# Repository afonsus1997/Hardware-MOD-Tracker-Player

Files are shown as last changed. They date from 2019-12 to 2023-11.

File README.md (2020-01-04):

# Hardware MOD Tracker Player

## How to setup the ST ARM toolchain and IDE

* [Download the GNU toolchain from arm](https://developer.arm.com/tools-and-software/open-source-software/developer-tools/gnu-toolchain/gnu-rm/downloads)

* Uninstall old packages 

```sudo apt remove binutils-arm-none-eabi gcc-arm-none-eabi libnewlib-arm-none-eabi```

* Untar package to desired directory (ex: ~/arm/)

```tar -xjvf gcc-arm-none-eabi-xxxxxxxxx```

* Add toolchain to path

```export PATH=$PATH:"PATH TO TOOLCHAIN"/bin/```

* Test arm-gcc

```arm-none-eabi-gcc --version```

### VSCODE Setup

* Install ```stm32-for-vscode``` plugin

* Install ```Cortex-Debug extension``` plugin

### Install STLINK drivers

* Install Libusb

```sudo apt-get install libusb-1.0-0-dev```

* Install stlink ultility

```git clone https://github.com/texane/stlink stlink.git
cd stlink
make
#install binaries:
sudo cp build/Release/st-* /usr/local/bin
#install udev rules
sudo cp etc/udev/rules.d/49-stlinkv* /etc/udev/rules.d/
#and restart udev
sudo udevadm control --reload
```

### Install openOCD

```sudo apt-get install openocd```

### Install STM32CUBEMX (Optional but recommended)

For pinmaps, code generation, etc...

* [Download STM32CUBEMX](https://my.st.com/content/my_st_com/en/products/development-tools/software-development-tools/stm32-software-development-tools/stm32-configurators-and-code-generators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)

* unzip and cd to extracted

* Mark binary as executable

```chmod +x SetupSTM32CubeMX-x.x.x.linux```

* Run binary

```./SetupSTM32CubeMX-x.x.x.linux```

* Go through installation process on GUI

## How to flash STM project

### Using VScode

* Open project folder

* Open command list (Ctrl+Shift+p)

* Type ```stm32``` and choose an option

### Using make

* Build

```make -f STM32Make.make```

* Build and flash

```make -f STM32Make.make flash```

* Clean 

```make -f STM32Make.make clean```

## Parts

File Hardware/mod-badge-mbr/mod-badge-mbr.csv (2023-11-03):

Source: | E:\Github\Hardware-MOD-Tracker-Player\Hardware\mod-badge-mbr\mod-badge-mbr.kicad_sch
Date: | 11/3/2023 1:12:24 AM
Tool: | Eeschema 7.0.7
Generator: | C:\Program Files\KiCad\7.0\bin\scripting\plugins/bom_csv_grouped_by_value_with_fp.py
Component Count: | 71
Ref | Qnty | Value | Cmp name | Footprint | Description | Vendor | DNP
BT1 | 1 | Battery | Battery | mod:AAA-HOLDER-THD | Multiple-cell battery
C1, C2, C22 | 3 | 28uF | C_Small | Capacitor_SMD:C_0603_1608Metric | Unpolarized capacitor, small symbol
C3, C4, C6, C7, C8, C9, C10, C11, C12, C14, C17, C19 | 12 | 100n | C_Small | Capacitor_SMD:C_0603_1608Metric | Unpolarized capacitor, small symbol
C5, C13 | 2 | 1u | C_Small | Capacitor_SMD:C_0603_1608Metric | Unpolarized capacitor, small symbol
C15, C16 | 2 | 27p | C_Small | Capacitor_SMD:C_0603_1608Metric | Unpolarized capacitor, small symbol
C18 | 1 | 10u | C_Small | Capacitor_SMD:C_0603_1608Metric | Unpolarized capacitor, small symbol
C20, C21 | 2 | 220p | C_Small | Capacitor_SMD:C_0603_1608Metric | Unpolarized capacitor, small symbol
D1, D2, D3, D15 | 4 | D_Schottky | D_Schottky | Diode_SMD:D_SOD-123 | Schottky diode
J1 | 1 | USB_C_Receptacle_USB2.0 | USB_C_Receptacle_USB2.0 | Connector_USB:USB_C_Receptacle_HCTL_HC-TYPE-C-16P-01A | USB 2.0-only Type-C Receptacle connector
J2 | 1 | Micro_SD_Card_Det1 | Micro_SD_Card_Det1 | mod:J_sd_micro_socket | Micro SD Card Socket with one card detection pin
J3 | 1 | Conn_01x03_MountingPin | Conn_01x03_MountingPin | Connector_JST:JST_SH_SM03B-SRSS-TB_1x03-1MP_P1.00mm_Horizontal | Generic connectable mounting pin connector, single row, 01x03, script generated (kicad-library-utils/schlib/autogen/connector/)
J4, J5 | 2 | Conn_01x01_Pin | Conn_01x01_Pin | TestPoint:TestPoint_Keystone_5015_Micro-Minature | Generic connector, single row, 01x01, script generated
J7 | 1 | Conn_02x06_Odd_Even | Conn_02x06_Odd_Even | Connector_PinHeader_2.54mm:PinHeader_2x06_P2.54mm_Vertical_SMD | Generic connector, double row, 02x06, odd/even pin numbering scheme (row 1 odd numbers, row 2 even numbers), script generated (kicad-library-utils/schlib/autogen/connector/)
L1 | 1 | 22uH | L | Inductor_SMD:L_Changjiang_FNR5040S | Inductor
Q2 | 1 | AO3401A | AO3401A | Package_TO_SOT_SMD:SOT-23 | -4.0A Id, -30V Vds, P-Channel MOSFET, SOT-23
R1 | 1 | 11.5k | R | Resistor_SMD:R_0603_1608Metric | Resistor
R2 | 1 | 2.55k | R | Resistor_SMD:R_0603_1608Metric | Resistor
R3 | 1 | R | R | Resistor_SMD:R_0603_1608Metric | Resistor
R5 | 1 | 10k | R | Resistor_SMD:R_0603_1608Metric | Resistor
R6, R7 | 2 | 5.1k | R | Resistor_SMD:R_0603_1608Metric | Resistor
R8, R13, R14 | 3 | DNI | R | Resistor_SMD:R_0603_1608Metric | Resistor
R9 | 1 | 1k | R | Resistor_SMD:R_0603_1608Metric | Resistor
R10 | 1 | 1k | R | Resistor_SMD:R_0402_1005Metric | Resistor
R11, R12 | 2 | 27.4 | R | Resistor_SMD:R_0402_1005Metric | Resistor
R18, R19, R20, R22, R23, R24, R33 | 7 | 0 | R | Resistor_SMD:R_0603_1608Metric | Resistor
R21 | 1 | 1M | R | Resistor_SMD:R_0603_1608Metric | Resistor
RN1 | 1 | 4x1k | R_Pack04 | Resistor_SMD:R_Array_Convex_4x0402 | 4 resistor network, parallel topology
RN2 | 1 | R_Pack04_Split | R_Pack04_Split | Resistor_SMD:R_Array_Convex_4x0402 | 4 resistor network, parallel topology, split
RV1 | 1 | R_Potentiometer | R_Potentiometer | mod:gear-dial-pot-3pin | Potentiometer
SW2, SW3, SW4, SW5, SW6 | 5 | SW_MEC_5E | SW_MEC_5E | mod:SW_SKRPACE010 | MEC 5E single pole normally-open tactile switch
SW7 | 1 | SW_Push_DPDT | SW_Push_DPDT | mod:SS-3235S-L2 | Momentary Switch, dual pole double throw
U1 | 1 | RP2040 | RP2040 | Package_DFN_QFN:QFN-56-1EP_7x7mm_P0.4mm_EP3.2x3.2mm | A microcontroller by Raspberry Pi
U2 | 1 | MT3608 | MT3608 | Package_TO_SOT_SMD:SOT-23-6 | High Efficiency 1.2MHz 2A Step Up Converter, 2-24V Vin, 28V Vout, 4A current limit, 1.2MHz, SOT23-6
U3 | 1 | AMS1117-3.3 | AMS1117-3.3 | Package_TO_SOT_SMD:SOT-223-3_TabPin2 | 1A Low Dropout regulator, positive, 3.3V fixed output, SOT-223
U4 | 1 | W25Q32JVSS | W25Q32JVSS | Package_SO:SOIC-8_5.23x5.23mm_P1.27mm | 32Mb Serial Flash Memory, Standard/Dual/Quad SPI, SOIC-8
U5 | 1 | MAX98357AETE_T | MAX98357AETE_T | mod:QFN50P300X300X80-17N
Y1 | 1 | 12MHZ | Crystal_GND24_Small | Crystal:Crystal_SMD_3225-4Pin_3.2x2.5mm | Four pin crystal, GND on pins 2 and 4, small symbol

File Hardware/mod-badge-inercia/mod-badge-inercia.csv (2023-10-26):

Source: | C:\Users\afons\Documents\kicad-ws\mod-player\mod-player.kicad_sch
Date: | 10/15/2023 2:59:10 PM
Tool: | Eeschema 7.0.7
Generator: | C:\Program Files\KiCad\7.0\bin\scripting\plugins/bom_csv_grouped_by_value_with_fp.py
Component Count: | 119
Ref | Qnty | Value | Cmp name | Footprint | Description | Vendor | DNP
BT1 | 1 | Battery | Battery | mod:AAA-HOLDER-THD | Multiple-cell battery
C1, C2, C22 | 3 | 28uF | C_Small | Capacitor_SMD:C_0603_1608Metric | Unpolarized capacitor, small symbol
C3, C4, C6, C7, C8, C9, C10, C11, C12, C14, C17, C19 | 12 | 100n | C_Small | Capacitor_SMD:C_0603_1608Metric | Unpolarized capacitor, small symbol
C5, C13 | 2 | 1u | C_Small | Capacitor_SMD:C_0603_1608Metric | Unpolarized capacitor, small symbol
C15, C16 | 2 | 27p | C_Small | Capacitor_SMD:C_0603_1608Metric | Unpolarized capacitor, small symbol
C18 | 1 | 10u | C_Small | Capacitor_SMD:C_0603_1608Metric | Unpolarized capacitor, small symbol
C20, C21 | 2 | 220p | C_Small | Capacitor_SMD:C_0603_1608Metric | Unpolarized capacitor, small symbol
D1, D2, D3, D14 | 4 | D_Schottky | D_Schottky | Diode_SMD:D_SOD-123 | Schottky diode
D4, D5, D6, D7, D8, D9, D10, D11, D12, D13 | 10 | LED_ABGR | LED_ABGR | LED_SMD:LED_RGB_Everlight_EASV3015RGBA0_Horizontal | RGB LED, anode/blue/green/red
J1 | 1 | USB_C_Receptacle_USB2.0 | USB_C_Receptacle_USB2.0 | Connector_USB:USB_C_Receptacle_HCTL_HC-TYPE-C-16P-01A | USB 2.0-only Type-C Receptacle connector
J2 | 1 | Micro_SD_Card_Det1 | Micro_SD_Card_Det1 | mod:J_sd_micro_socket | Micro SD Card Socket with one card detection pin
J3 | 1 | Conn_01x03_MountingPin | Conn_01x03_MountingPin | Connector_JST:JST_SH_BM03B-SRSS-TB_1x03-1MP_P1.00mm_Vertical | Generic connectable mounting pin connector, single row, 01x03, script generated (kicad-library-utils/schlib/autogen/connector/)
J4, J5 | 2 | Conn_01x01_Pin | Conn_01x01_Pin | TestPoint:TestPoint_Keystone_5019_Minature | Generic connector, single row, 01x01, script generated
L1, L2 | 2 | 22uH | L | Inductor_SMD:L_Changjiang_FNR5040S | Inductor
Q1, Q2 | 2 | AO3401A | AO3401A | Package_TO_SOT_SMD:SOT-23 | -4.0A Id, -30V Vds, P-Channel MOSFET, SOT-23
Q3 | 1 | NMOS | NMOS | Package_TO_SOT_SMD:SOT-23 | N-MOSFET transistor, drain/source/gate
R1, R30 | 2 | 11.5k | R | Resistor_SMD:R_0603_1608Metric | Resistor
R2, R31 | 2 | 2.55k | R | Resistor_SMD:R_0603_1608Metric | Resistor
R3, R4, R28, R29 | 4 | R | R | Resistor_SMD:R_0603_1608Metric | Resistor
R5, R41, R47 | 3 | 10k | R | Resistor_SMD:R_0603_1608Metric | Resistor
R6, R7 | 2 | 5.1k | R | Resistor_SMD:R_0603_1608Metric | Resistor
R8, R13, R14 | 3 | DNI | R | Resistor_SMD:R_0603_1608Metric | Resistor
R9, R15, R16, R17 | 4 | 1k | R | Resistor_SMD:R_0603_1608Metric | Resistor
R10 | 1 | 1k | R | Resistor_SMD:R_0402_1005Metric | Resistor
R11, R12 | 2 | 27.4 | R | Resistor_SMD:R_0402_1005Metric | Resistor
R19, R22, R23, R24, R32, R33, R34, R35, R36, R48, R49, R50, R52, R53 | 14 | 0 | R | Resistor_SMD:R_0603_1608Metric | Resistor
R21 | 1 | 1M | R | Resistor_SMD:R_0603_1608Metric | Resistor
R25, R26, R37, R38, R39, R40, R42, R43, R44, R45 | 10 | 33 | R | Resistor_SMD:R_0603_1608Metric | Resistor
RV1 | 1 | R_Potentiometer | R_Potentiometer | mod:gear-dial-pot-3pin | Potentiometer
SW2, SW3, SW4, SW5, SW6 | 5 | SW_MEC_5E | SW_MEC_5E | mod:SW_SKRPACE010 | MEC 5E single pole normally-open tactile switch
SW7 | 1 | SW_Push_DPDT | SW_Push_DPDT | Button_Switch_SMD:SW_DPDT_CK_JS202011JCQN | Momentary Switch, dual pole double throw
U1 | 1 | RP2040 | RP2040 | Package_DFN_QFN:QFN-56-1EP_7x7mm_P0.4mm_EP3.2x3.2mm | A microcontroller by Raspberry Pi
U2, U7 | 2 | MT3608 | MT3608 | Package_TO_SOT_SMD:SOT-23-6 | High Efficiency 1.2MHz 2A Step Up Converter, 2-24V Vin, 28V Vout, 4A current limit, 1.2MHz, SOT23-6
U3 | 1 | AMS1117-3.3 | AMS1117-3.3 | Package_TO_SOT_SMD:SOT-223-3_TabPin2 | 1A Low Dropout regulator, positive, 3.3V fixed output, SOT-223
U4 | 1 | W25Q32JVSS | W25Q32JVSS | Package_SO:SOIC-8_5.23x5.23mm_P1.27mm | 32Mb Serial Flash Memory, Standard/Dual/Quad SPI, SOIC-8
U5 | 1 | MAX98357AETE_T | MAX98357AETE_T | mod:QFN50P300X300X80-17N
U6, U8, U9, U10, U11, U12, U13, U14, U15, U16 | 10 | WS2811 | WS2811 | Package_TO_SOT_SMD:SOT-23-8 | 3-Channel 8-Bit PWM LED Driver, DIP-8/SOIC-8
Y1 | 1 | 12MHZ | Crystal_GND24_Small | Crystal:Crystal_SMD_3225-4Pin_3.2x2.5mm | Four pin crystal, GND on pins 2 and 4, small symbol

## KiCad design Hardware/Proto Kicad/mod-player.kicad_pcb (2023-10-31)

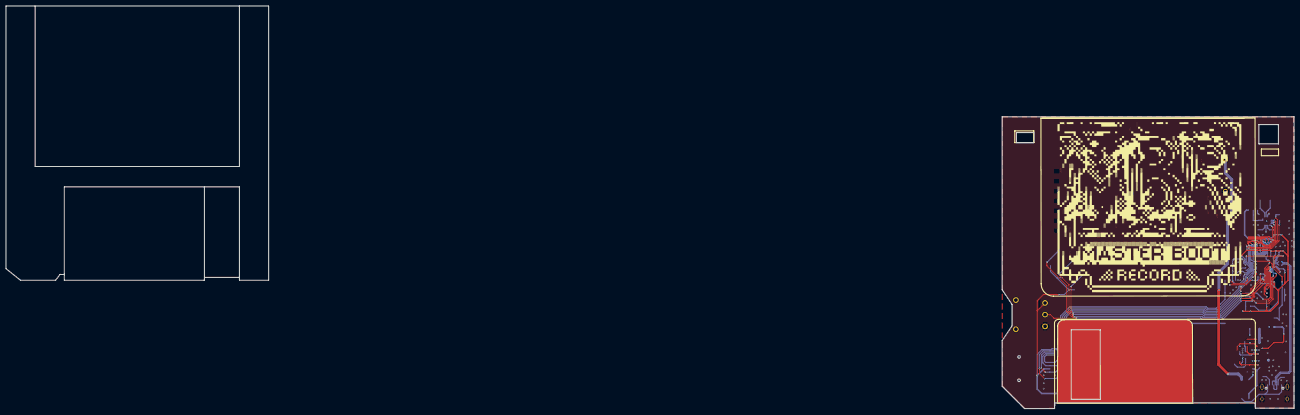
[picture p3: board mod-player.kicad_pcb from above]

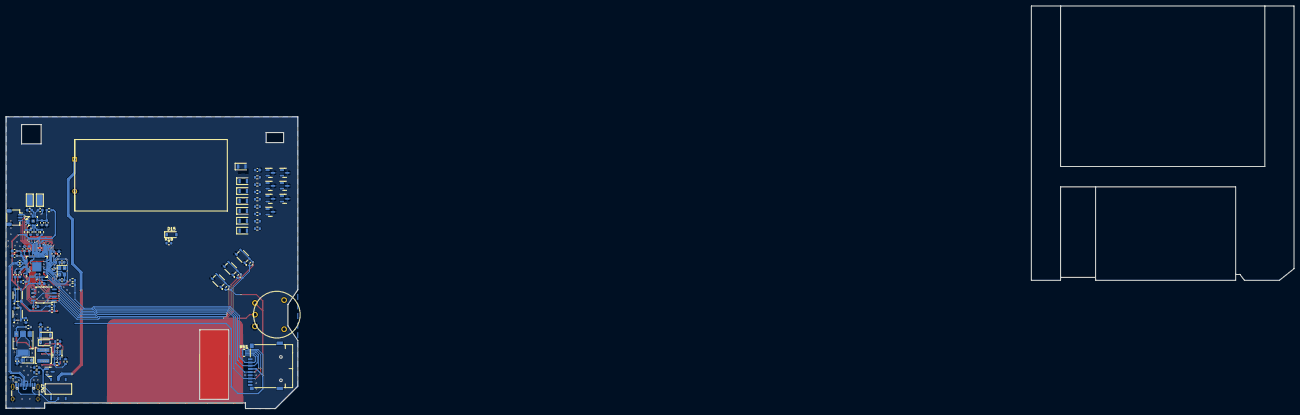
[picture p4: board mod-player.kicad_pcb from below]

Board: 4 copper layers, 100.0 x 100.0 mm, 95 parts (95 on the bottom side), 66 nets.

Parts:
BT1: Battery; AAA-HOLDER-THD
C1, C2, C22: 28uF; C_0603_1608Metric
C3, C4, C6, C7, C8, C9, C10, C11, C12, C14, C17, C19: 100n; C_0603_1608Metric
C5, C13: 1u; C_0603_1608Metric
C15, C16: 27p; C_0603_1608Metric
C18: 10u; C_0603_1608Metric
C20, C21: 220p; C_0603_1608Metric
D1, D2, D3, D15: D_Schottky; D_SOD-123
D4, D5, D6, D7, D8, D9, D10: LED; 1206_reverse_xinglight
J1: USB_C_Receptacle_USB2.0; USB_C_Receptacle_HCTL_HC-TYPE-C-16P-01A
J2: Micro_SD_Card_Det1; J_sd_micro_socket
J3: Conn_01x03_MountingPin; JST_SH_SM03B-SRSS-TB_1x03-1MP_P1.00mm_Horizontal
J4, J5: Conn_01x01_Pin; TestPoint_Keystone_5019_Minature
L1: 22uH; L_Changjiang_FNR5040S
Q1, Q3, Q4, Q5, Q6, Q7, Q8: NMOS; SOT-23
Q2: AO3401A; SOT-23
R1: 11.5k; R_0603_1608Metric
R2: 2.55k; R_0603_1608Metric
R3, R4: R; R_0603_1608Metric
R5: 10k; R_0603_1608Metric
R6, R7: 5.1k; R_0603_1608Metric
R8, R13, R14: DNI; R_0603_1608Metric
R9, R15, R16, R17, R25, R26, R27, R28, R29, R30, R31: 1k; R_0603_1608Metric
R10: 1k; R_0402_1005Metric
R11, R12: 27.4; R_0402_1005Metric
R18, R19, R20, R22, R23, R24, R33, R53: 0; R_0603_1608Metric
R21: 1M; R_0603_1608Metric
RN1: 4x1k; R_Array_Convex_4x0402
RV1: R_Potentiometer; gear-dial-pot-3pin
SW2, SW3, SW4, SW5, SW6: SW_MEC_5E; SW_SKRPACE010
SW7: SW_Push_DPDT; SS-3235S-L2
U1: RP2040; QFN-56-1EP_7x7mm_P0.4mm_EP3.2x3.2mm
U2: MT3608; SOT-23-6
U3: AMS1117-3.3; SOT-223-3_TabPin2
U4: W25Q32JVSS; SOIC-8_5.23x5.23mm_P1.27mm
U5: MAX98357AETE_T; QFN50P300X300X80-17N
Y1: 12MHZ; Crystal_SMD_3225-4Pin_3.2x2.5mm

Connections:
+1V1: C3.1, C4.1, C5.1, U1.23 (DVDD), U1.45 (VREG_VOUT), U1.50 (DVDD)
+3V3: C6.1, C7.1, C8.1, C9.1, C10.1, C11.1, C12.1, C13.1, C14.1, J2.4 (VDD), R8.1, R15.2, R16.2, R17.2, R21.1, R22.1, R24.2, R25.1, R26.1, R27.1, R28.1, R29.1, R30.1, R31.1, R53.2, RN1.1 (R1.1), RN1.2 (R2.1), RN1.3 (R3.1), RN1.4 (R4.1), RV1.1, U1.1 (IOVDD), U1.10 (IOVDD), U1.22 (IOVDD), U1.33 (IOVDD), U1.42 (IOVDD), U1.43 (ADC_AVDD), U1.44 (VREG_IN), U1.48 (USB_VDD), U1.49 (IOVDD), U4.8 (VCC)
+5V: D15.1 (K), R33.2, U3.3 (VI)
+BATT: Q2.2 (S), SW7.6 (C)
/3v3_boost: C1.1, D1.1 (K), D3.2 (A), R1.1, R18.1
/3v3_ldo: C2.1, D2.2 (A), R20.1, U3.2 (VO)
/GAIN: R22.2, R23.2, U5.2 (GAIN_SLOT)
/I2S_BCLK: U1.31 (GPIO20), U5.16 (BCLK)
/I2S_DIN: U1.34 (GPIO22), U5.1 (DIN)
/I2S_LRC: U1.32 (GPIO21), U5.14 (LRCLK)
/MCU_SWCLK: J3.1, U1.24 (SWCLK)
/MCU_SWD: J3.3, U1.25 (SWD)
/QSPI_SCLK: U1.52 (QSPI_SCLK), U4.6 (CLK)
/QSPI_SD0: U1.53 (QSPI_SD0), U4.5 (DI(IO0))
/QSPI_SD1: U1.55 (QSPI_SD1), U4.2 (DO(IO1))
/QSPI_SD2: U1.54 (QSPI_SD2), U4.3 (IO2)
/QSPI_SD3: U1.51 (QSPI_SD3), U4.7 (IO3)
/QSPI_SS: R8.2, R9.2, U1.56 (QSPI_SS), U4.1 (~CS)
/RUN: C17.1, SW2.3 (K), SW2.4 (A), U1.26 (RUN)
/SD_MODE: R19.2, R21.2, U5.4 (SD_MODE)
/SPI_1_CS: J2.2 (DAT3/CD), R13.2, R14.2, RN1.5 (R4.2)
/SPI_1_MISO: J2.7 (DAT0), RN1.8 (R1.2), U1.15 (GPIO12)
/SPI_1_MOSI: J2.3 (CMD), RN1.6 (R3.2), U1.18 (GPIO15)
/SPI_1_SCK: J2.5 (CLK), RN1.7 (R2.2), U1.17 (GPIO14)
/SPK_OUT_N: C21.2, J5.1, U5.10 (OUTN)
/SPK_OUT_P: C20.2, J4.1, U5.9 (OUTP)
/SW1: R15.1, SW4.3 (K), SW4.4 (A), U1.6 (GPIO4)
/SW2: R16.1, SW5.3 (K), SW5.4 (A), U1.7 (GPIO5)
/SW3: R17.1, SW6.3 (K), SW6.4 (A), U1.8 (GPIO6)
/USB_D_N: J1.A7 (D-), J1.B7 (D-), R12.1
/USB_D_P: J1.A6 (D+), J1.B6 (D+), R11.1
/VBAT_IN: BT1.1 (+), SW7.5 (B)
/VBUS_IN: J1.A4 (VBUS), J1.A9 (VBUS), J1.B4 (VBUS), J1.B9 (VBUS), SW7.2 (B)
/~USB_BOOT: R9.1, SW3.3 (K), SW3.4 (A)
GND: BT1.2 (-), C1.2, C2.2, C3.2, C4.2, C5.2, C6.2, C7.2, C8.2, C9.2, C10.2, C11.2, C12.2, C13.2, C14.2, C15.1, C16.1, C17.2, C18.1, C19.1, C20.1, C21.1, C22.2, J1.A1 (GND), J1.A12 (GND), J1.B1 (GND), J1.B12 (GND), J1.S1 (SHIELD), J2.6 (VSS), J3.2, J3.MP (MountPin), Q1.3 (S), Q3.3 (S), Q4.3 (S), Q5.3 (S), Q6.3 (S), Q7.3 (S), Q8.3 (S), R2.2, R4.2, R5.2, R6.2, R7.2, R19.1, R23.1, RV1.3, SW2.1, SW2.2, SW3.1, SW3.2, SW4.1, SW4.2, SW5.1, SW5.2, SW6.1, SW6.2, U1.19 (TESTEN), U1.57 (GND), U2.2 (GND), U3.1 (GND), U4.4 (GND), U5.3 (GND), U5.11 (GND), U5.15 (GND), Y1.2, Y1.4
unnamed: C16.2, R10.1, Y1.1
unnamed: C18.2, C19.2, R53.1, U5.7 (VDD), U5.8 (VDD)
unnamed: D1.2 (A), L1.2, U2.1 (SW)
unnamed: D2.1 (K), D3.1 (K), R18.2, R20.2, R24.1
unnamed: D4.2 (A), R25.2
unnamed: D4.1 (K), Q1.1 (D)
unnamed: D5.2 (A), R26.2
unnamed: D5.1 (K), Q3.1 (D)
unnamed: D6.2 (A), R27.2
unnamed: D6.1 (K), Q4.1 (D)
unnamed: D7.2 (A), R28.2
unnamed: D7.1 (K), Q5.1 (D)
unnamed: D8.2 (A), R29.2
unnamed: D8.1 (K), Q6.1 (D)
unnamed: D9.2 (A), R30.2
unnamed: D9.1 (K), Q7.1 (D)
unnamed: D10.2 (A), R31.2
unnamed: D10.1 (K), Q8.1 (D)
unnamed: J1.A5 (CC1), R7.1
unnamed: J1.B5 (CC2), R6.1
unnamed: C22.1, L1.1, Q2.3 (D), R3.1, U2.5 (IN)
unnamed: R13.1, U1.12 (GPIO9)
unnamed: R14.1, U1.16 (GPIO13)
unnamed: RV1.2, U1.38 (GPIO26_ADC0)
unnamed: R12.2, U1.46 (USB_DM)
unnamed: R11.2, U1.47 (USB_DP)
unnamed: C15.2, U1.20 (XIN), Y1.3
unnamed: R10.2, U1.21 (XOUT)
unnamed: R3.2, R4.1, U2.4 (EN)
unnamed: R1.2, R2.1, U2.3 (FB)
VBUS: D15.2 (A), Q2.1 (G), R5.1, R33.1, SW7.3 (C)

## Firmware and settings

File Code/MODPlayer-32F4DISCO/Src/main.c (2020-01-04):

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

/* Includes ------------------------------------------------------------------*/
#include "main.h"
#include "usb_host.h"

/* USER CODE BEGIN PM */
#include "../Lib/HxCMOD/hxcmod.h"
#include "../../Drivers/DISCO/stm32412g_discovery_lcd.h"
#include "../../Drivers/DISCO/stm32412g_discovery_audio.h"
#include "../../Drivers/DISCO/stm32412g_discovery.h"
/* USER CODE END PM */

I2C_HandleTypeDef hi2c1;
I2C_HandleTypeDef hi2c2;

I2S_HandleTypeDef hi2s3;
DMA_HandleTypeDef hdma_spi3_tx;

QSPI_HandleTypeDef hqspi;

SD_HandleTypeDef hsd;

SPI_HandleTypeDef hspi1;

UART_HandleTypeDef huart2;

SRAM_HandleTypeDef hsram1;

/* USER CODE BEGIN PV */
#define LCD_SCREEN_WIDTH              240
#define LCD_SCREEN_HEIGHT             240
#define RGB565_BYTE_PER_PIXEL         2

#define PLAYER_SAMPLE_RATE 48000

// Mod player context
modcontext mcontext;

#define SAMPLE_BUFFER_SIZE 8192
msample dmasoundbuffer[SAMPLE_BUFFER_SIZE] __attribute__ ((aligned (4)));

extern const unsigned char mod_data[39424];

uint8_t uwInternelBuffer[LCD_SCREEN_WIDTH*LCD_SCREEN_HEIGHT*RGB565_BYTE_PER_PIXEL];



/* USER CODE END PV */

void SystemClock_Config(void);
static void MX_GPIO_Init(void);
static void MX_FSMC_Init(void);
static void MX_I2C1_Init(void);
static void MX_I2C2_Init(void);
static void MX_I2S3_Init(void);
static void MX_QUADSPI_Init(void);
static void MX_SDIO_SD_Init(void);
static void MX_USART2_UART_Init(void);
static void MX_SPI1_Init(void);
static void MX_DMA_Init(void);
void MX_USB_HOST_Process(void);

/* USER CODE BEGIN 0 */

BSP_AUDIO_OUT_HalfTransfer_CallBack(hi2s3){
	int i;
	/* Prevent unused argument(s) compilation warning */

	hxcmod_fillbuffer( &mcontext, (msample*)&dmasoundbuffer, SAMPLE_BUFFER_SIZE/2, NULL );

	// 16 to 12 bits conversion to match with the STM32 DAC.
	for(i=0;i<SAMPLE_BUFFER_SIZE/2;i++)
		dmasoundbuffer[i] = dmasoundbuffer[i] >> 4;
}

 BSP_AUDIO_OUT_TransferComplete_CallBack(){
	int i;

	hxcmod_fillbuffer( &mcontext, (msample*)&dmasoundbuffer[SAMPLE_BUFFER_SIZE/2], SAMPLE_BUFFER_SIZE/2, NULL );

	// 16 to 12 bits conversion to match with the STM32 DAC.
	for(i=0;i<SAMPLE_BUFFER_SIZE/2;i++)
		dmasoundbuffer[(SAMPLE_BUFFER_SIZE/2) + i] = dmasoundbuffer[(SAMPLE_BUFFER_SIZE/2) + i] >> 4;

}

/* USER CODE END 0 */

/**
	* @brief  The application entry point.
	* @retval int
	*/
int main(void)
{
	

	/* MCU Configuration--------------------------------------------------------*/

	/* Reset of all peripherals, Initializes the Flash interface and the Systick. */
	HAL_Init();

	/* Configure the system clock */
	SystemClock_Config();

	/* Initialize all configured peripherals */
	MX_GPIO_Init();
	MX_FSMC_Init();
	MX_I2C1_Init();
	MX_I2C2_Init();
	MX_I2S3_Init();
	MX_QUADSPI_Init();
	MX_SDIO_SD_Init();
	MX_USART2_UART_Init();
	MX_USB_HOST_Init();
	MX_SPI1_Init();
	MX_DMA_Init();
	/* USER CODE BEGIN 2 */

	BSP_LED_Init(LED3);

	BSP_LCD_Init();
  
  /* Clear the LCD */
  BSP_LCD_Clear(LCD_COLOR_WHITE);

	BSP_AUDIO_OUT_Init(OUTPUT_DEVICE_HEADPHONE1, 64, I2S_AUDIOFREQ_48K);

	hxcmod_init( &mcontext );

	hxcmod_setcfg( &mcontext, PLAYER_SAMPLE_RATE, 0, 0);

  hxcmod_load( &mcontext, (void*)&mod_data, sizeof(mod_data) );
	int i;
	for(i=0;i<SAMPLE_BUFFER_SIZE;i++)
  {
    dmasoundbuffer[i] = 2048;
  }

	hxcmod_fillbuffer( &mcontext, (msample*)&dmasoundbuffer[SAMPLE_BUFFER_SIZE/2], SAMPLE_BUFFER_SIZE/2, NULL );
  
	HAL_I2S_Transmit_DMA(&hi2s3, (uint32_t*)&dmasoundbuffer, SAMPLE_BUFFER_SIZE);
	/* USER CODE END 2 */

	/* Infinite loop */
	/* USER CODE BEGIN WHILE */
	while (1)
	{
	/* USER CODE END WHILE */
	MX_USB_HOST_Process();

	/* USER CODE BEGIN 3 */
	}
	/* USER CODE END 3 */
}

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


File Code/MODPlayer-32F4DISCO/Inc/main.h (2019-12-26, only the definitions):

#define LED3_Pin GPIO_PIN_2
#define LED3_GPIO_Port GPIOE
#define LED4_Pin GPIO_PIN_3
#define LED4_GPIO_Port GPIOE
#define DFSDM_DATIN3_Pin GPIO_PIN_4
#define DFSDM_DATIN3_GPIO_Port GPIOE
#define A0_Pin GPIO_PIN_0
#define A0_GPIO_Port GPIOF
#define LCD_BLCTRL_Pin GPIO_PIN_5
#define LCD_BLCTRL_GPIO_Port GPIOF
#define QSPI_BK1_IO3_Pin GPIO_PIN_6
#define QSPI_BK1_IO3_GPIO_Port GPIOF
#define QSPI_BK1_IO2_Pin GPIO_PIN_7
#define QSPI_BK1_IO2_GPIO_Port GPIOF
#define QSPI_BK1_IO0_Pin GPIO_PIN_8
#define QSPI_BK1_IO0_GPIO_Port GPIOF
#define QSPI_BK1_IO1_Pin GPIO_PIN_9
#define QSPI_BK1_IO1_GPIO_Port GPIOF
#define STLK_MCO_Pin GPIO_PIN_0
#define STLK_MCO_GPIO_Port GPIOH
#define DFSDM_CKOUT_Pin GPIO_PIN_2
#define DFSDM_CKOUT_GPIO_Port GPIOC
#define JOY_SEL_Pin GPIO_PIN_0
#define JOY_SEL_GPIO_Port GPIOA
#define STLINK_RX_Pin GPIO_PIN_2
#define STLINK_RX_GPIO_Port GPIOA
#define STLINK_TX_Pin GPIO_PIN_3
#define STLINK_TX_GPIO_Port GPIOA
#define CODEC_I2S3_WS_Pin GPIO_PIN_4
#define CODEC_I2S3_WS_GPIO_Port GPIOA
#define DFSDM_DATIN0_Pin GPIO_PIN_1
#define DFSDM_DATIN0_GPIO_Port GPIOB
#define QSPI_CLK_Pin GPIO_PIN_2
#define QSPI_CLK_GPIO_Port GPIOB
#define EXT_RESET_Pin GPIO_PIN_11
#define EXT_RESET_GPIO_Port GPIOF
#define CTP_RST_Pin GPIO_PIN_12
#define CTP_RST_GPIO_Port GPIOF
#define JOY_RIGHT_Pin GPIO_PIN_14
#define JOY_RIGHT_GPIO_Port GPIOF
#define JOY_LEFT_Pin GPIO_PIN_15
#define JOY_LEFT_GPIO_Port GPIOF
#define JOY_UP_Pin GPIO_PIN_0
#define JOY_UP_GPIO_Port GPIOG
#define JOY_DOWN_Pin GPIO_PIN_1
#define JOY_DOWN_GPIO_Port GPIOG
#define D4_Pin GPIO_PIN_7
#define D4_GPIO_Port GPIOE
#define D5_Pin GPIO_PIN_8
#define D5_GPIO_Port GPIOE
#define D6_Pin GPIO_PIN_9
#define D6_GPIO_Port GPIOE
#define D7_Pin GPIO_PIN_10
#define D7_GPIO_Port GPIOE
#define D8_Pin GPIO_PIN_11
#define D8_GPIO_Port GPIOE
#define D9_Pin GPIO_PIN_12
#define D9_GPIO_Port GPIOE
#define D10_Pin GPIO_PIN_13
#define D10_GPIO_Port GPIOE
#define D11_Pin GPIO_PIN_14
#define D11_GPIO_Port GPIOE
#define D12_Pin GPIO_PIN_15
#define D12_GPIO_Port GPIOE
#define I2C2_SCL_Pin GPIO_PIN_10
#define I2C2_SCL_GPIO_Port GPIOB
#define M2_CKIN_Pin GPIO_PIN_11
#define M2_CKIN_GPIO_Port GPIOB
#define CODEC_I2S3_SCK_Pin GPIO_PIN_12
#define CODEC_I2S3_SCK_GPIO_Port GPIOB
#define D13_Pin GPIO_PIN_8
#define D13_GPIO_Port GPIOD
#define D14_Pin GPIO_PIN_9
#define D14_GPIO_Port GPIOD
#define D15_Pin GPIO_PIN_10
#define D15_GPIO_Port GPIOD
#define LCD_RESET_Pin GPIO_PIN_11
#define LCD_RESET_GPIO_Port GPIOD
#define D0_Pin GPIO_PIN_14
#define D0_GPIO_Port GPIOD
#define D1_Pin GPIO_PIN_15
#define D1_GPIO_Port GPIOD
#define CODEC_INT_Pin GPIO_PIN_2
#define CODEC_INT_GPIO_Port GPIOG
#define LCD_TE_Pin GPIO_PIN_4
#define LCD_TE_GPIO_Port GPIOG
#define CTP_INT_Pin GPIO_PIN_5
#define CTP_INT_GPIO_Port GPIOG
#define QSPI_BK1_NCS_Pin GPIO_PIN_6
#define QSPI_BK1_NCS_GPIO_Port GPIOG
#define USB_OTGFS_OVRCR_Pin GPIO_PIN_7
#define USB_OTGFS_OVRCR_GPIO_Port GPIOG
#define USB_OTGFS_PPWR_EN_Pin GPIO_PIN_8
#define USB_OTGFS_PPWR_EN_GPIO_Port GPIOG
#define CODEC_I2S3_MCK_Pin GPIO_PIN_7
#define CODEC_I2S3_MCK_GPIO_Port GPIOC
#define uSD_D0_Pin GPIO_PIN_8
#define uSD_D0_GPIO_Port GPIOC
#define uSD_D1_Pin GPIO_PIN_9
#define uSD_D1_GPIO_Port GPIOC
#define M2_CKINA8_Pin GPIO_PIN_8
#define M2_CKINA8_GPIO_Port GPIOA
#define USB_OTGFS_VBUS_Pin GPIO_PIN_9
#define USB_OTGFS_VBUS_GPIO_Port GPIOA
#define USB_OTGFS_ID_Pin GPIO_PIN_10
#define USB_OTGFS_ID_GPIO_Port GPIOA
#define USB_OTGFS_DM_Pin GPIO_PIN_11
#define USB_OTGFS_DM_GPIO_Port GPIOA
#define USB_OTGFS_DP_Pin GPIO_PIN_12
#define USB_OTGFS_DP_GPIO_Port GPIOA
#define SWDIO_Pin GPIO_PIN_13
#define SWDIO_GPIO_Port GPIOA
#define SWCLK_Pin GPIO_PIN_14
#define SWCLK_GPIO_Port GPIOA
#define uSD_D2_Pin GPIO_PIN_10
#define uSD_D2_GPIO_Port GPIOC
#define uSD_D3_Pin GPIO_PIN_11
#define uSD_D3_GPIO_Port GPIOC
#define uSD_CLK_Pin GPIO_PIN_12
#define uSD_CLK_GPIO_Port GPIOC
#define D2_Pin GPIO_PIN_0
#define D2_GPIO_Port GPIOD
#define D3_Pin GPIO_PIN_1
#define D3_GPIO_Port GPIOD
#define uSD_CMD_Pin GPIO_PIN_2
#define uSD_CMD_GPIO_Port GPIOD
#define uSD_DETECT_Pin GPIO_PIN_3
#define uSD_DETECT_GPIO_Port GPIOD
#define FMC_NOE_Pin GPIO_PIN_4
#define FMC_NOE_GPIO_Port GPIOD
#define FMC_NWE_Pin GPIO_PIN_5
#define FMC_NWE_GPIO_Port GPIOD
#define FMC_NE1_Pin GPIO_PIN_7
#define FMC_NE1_GPIO_Port GPIOD
#define SWO_Pin GPIO_PIN_3
#define SWO_GPIO_Port GPIOB
#define CODEC_I2S3ext_SD_Pin GPIO_PIN_4
#define CODEC_I2S3ext_SD_GPIO_Port GPIOB
#define CODEC_I2S3_SD_Pin GPIO_PIN_5
#define CODEC_I2S3_SD_GPIO_Port GPIOB
#define I2C1_SCL_Pin GPIO_PIN_6
#define I2C1_SCL_GPIO_Port GPIOB
#define I2C1_SDA_Pin GPIO_PIN_7
#define I2C1_SDA_GPIO_Port GPIOB
#define I2C2_SDA_Pin GPIO_PIN_9
#define I2C2_SDA_GPIO_Port GPIOB
#define LED1_Pin GPIO_PIN_0
#define LED1_GPIO_Port GPIOE
#define LED2_Pin GPIO_PIN_1
#define LED2_GPIO_Port GPIOE

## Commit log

2019-12-26 added development project for 32f4disco board
2020-01-04 Added BSP board drivers for DISCO board. Setup LCD and audio
2023-10-26 added proto hardware
    [Mod-player-proto.PrjPcb, Sheet1.SchDoc, Sheet2.SchDoc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]
2023-10-31 hardware update
    [mod-player-B_Cu.gbl, mod-player-B_Mask.gbs, mod-player-B_Paste.gbp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]
2023-11-02 more hardware
    [mod-player.kicad_sch]
2023-11-02 added new hw projects
    [mod-badge-inercia-B_Cu.gbl, mod-badge-inercia-B_Mask.gbs, mod-badge-inercia-B_Paste.gbp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]
2023-11-03 boards exported and sent to fab
    [mod-badge-inercia-B_Mask.gbs, mod-badge-inercia-B_Paste.gbp, mod-badge-inercia-B_Silkscreen.gbo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]

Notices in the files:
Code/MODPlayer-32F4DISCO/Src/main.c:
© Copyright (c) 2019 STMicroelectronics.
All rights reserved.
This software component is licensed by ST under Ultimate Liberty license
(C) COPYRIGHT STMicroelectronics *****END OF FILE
